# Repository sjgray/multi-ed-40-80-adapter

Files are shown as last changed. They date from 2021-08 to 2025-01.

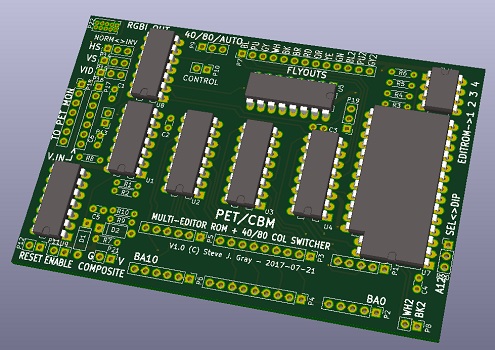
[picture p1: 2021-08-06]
multied4080.jpg

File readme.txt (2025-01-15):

PET/CBM Multi-EditROM with 40/80 column switcher Adapter
========================================================

This adapter lets your PET/CBM computer with Universal Dynamic PET motherboard
to have up to 16 Edit ROM available and selectable via DIP Switch or Toggle Switch.
and adds the ability for the video to be switched between 40 or 80 columns either
via software, or toggle switch (selectable).

Use my Multi-EDIT-ROM-Builder program (also available on github) to combine
up to 16 editor roms into a single 64K EPROM.

Use my PET/CBM EditROM Project to create custom Editor ROMs with various features
including software-switchable 40/80 column support via this board.

More information and assembly instructions at:
http://www.cbmsteve.ca
http://www.cbmsteve.ca/multied4080/index.html

Steve

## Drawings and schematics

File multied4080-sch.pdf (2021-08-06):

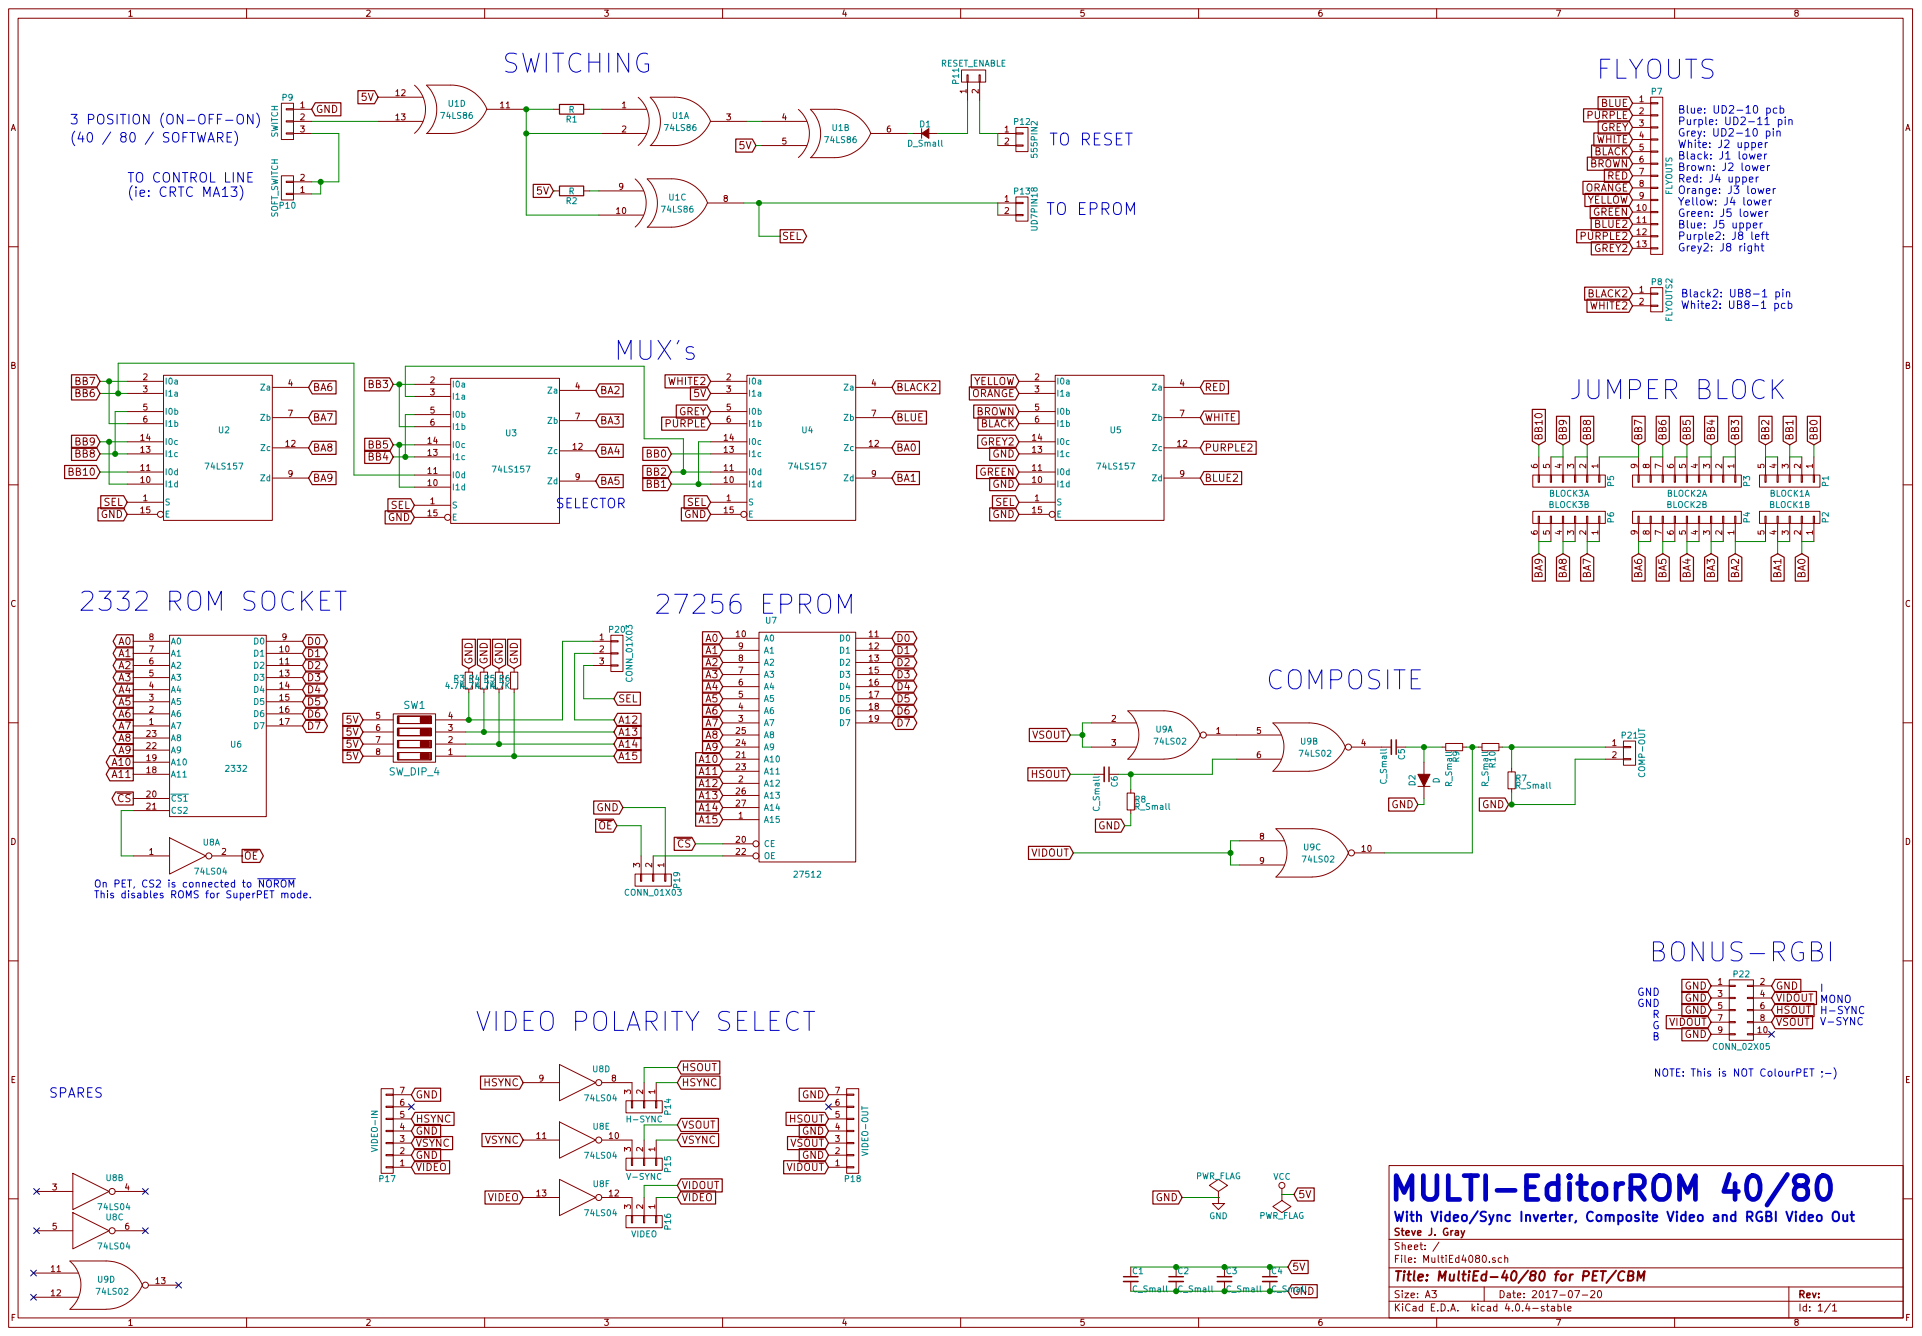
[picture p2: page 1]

3 POSITION (ON-OFF-ON)
(40 / 80 / SOFTWARE)

4.7K GND GND GND GND

On PET, CS2 is connected to NOROM
This disables ROMS for SuperPET mode.

NOTE: This is NOT ColourPET ;-)

File: MultiEd4080.sch Sheet: / Steve J. Gray

Id: 1/1 Title: MultiEd-40/80 for PET/CBM

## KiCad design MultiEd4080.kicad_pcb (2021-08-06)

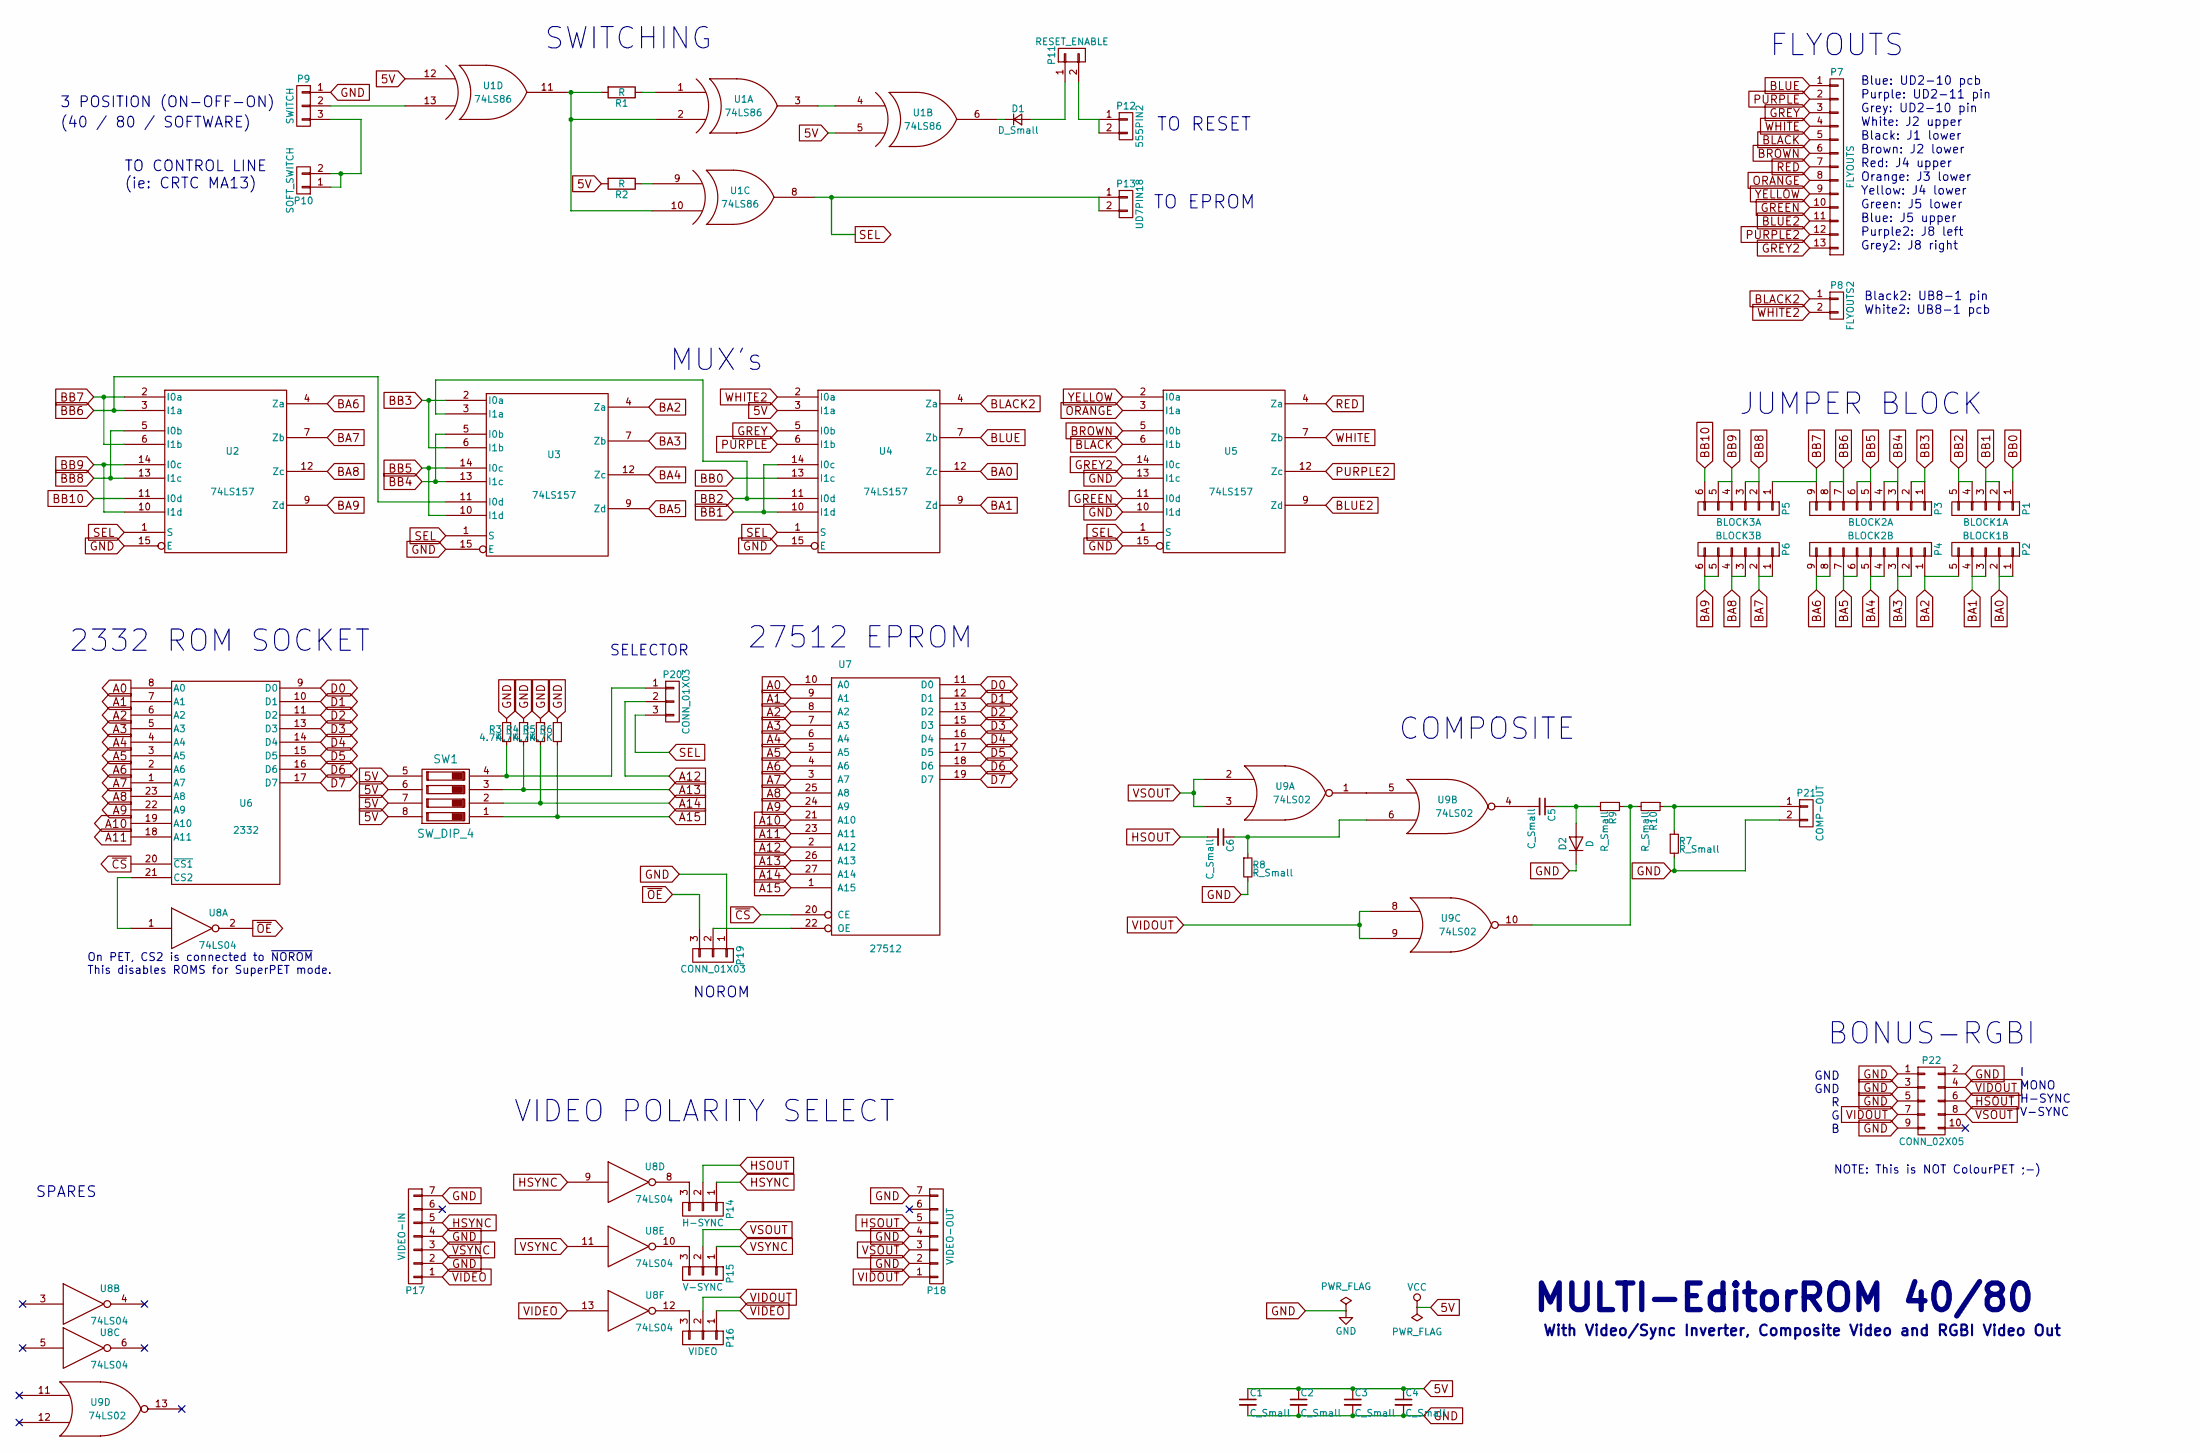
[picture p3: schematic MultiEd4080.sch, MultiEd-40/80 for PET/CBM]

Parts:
C1, C2, C3, C4, C5, C6: C_Small; C_Disc_D3.8mm_W2.6mm_P2.50mm
D1: D_Small; D_DO-41_SOD81_P7.62mm_Horizontal
D2: D; D_DO-41_SOD81_P7.62mm_Horizontal
P1: BLOCK1A; Pin_Header_Straight_1x05_Pitch2.54mm
P2: BLOCK1B; Pin_Header_Straight_1x05_Pitch2.54mm
P3: BLOCK2A; Pin_Header_Straight_1x09_Pitch2.54mm
P4: BLOCK2B; Pin_Header_Straight_1x09_Pitch2.54mm
P5: BLOCK3A; Pin_Header_Straight_1x06_Pitch2.54mm
P6: BLOCK3B; Pin_Header_Straight_1x06_Pitch2.54mm
P7: FLYOUTS; Pin_Header_Straight_1x13_Pitch2.54mm
P8: FLYOUTS2; Pin_Header_Straight_1x02_Pitch2.54mm
P9: SWITCH; Pin_Header_Straight_1x03_Pitch2.54mm
P10: SOFT_SWITCH; Pin_Header_Straight_1x02_Pitch2.54mm
P11: RESET_ENABLE; Pin_Header_Straight_1x02_Pitch2.54mm
P12: 555PIN2; Pin_Header_Straight_1x02_Pitch2.54mm
P13: UD7PIN18; Pin_Header_Straight_1x02_Pitch2.54mm
P14: H-SYNC; Pin_Header_Straight_1x03_Pitch2.54mm
P15: V-SYNC; Pin_Header_Straight_1x03_Pitch2.54mm
P16: VIDEO; Pin_Header_Straight_1x03_Pitch2.54mm
P17: VIDEO-IN; Pin_Header_Straight_1x07_Pitch2.54mm
P18: VIDEO-OUT; Pin_Header_Straight_1x07_Pitch2.54mm
P19, P20: CONN_01X03; Pin_Header_Straight_1x03_Pitch2.54mm
P21: COMP-OUT; Pin_Header_Straight_1x02_Pitch2.54mm
P22: CONN_02X05; Pin_Header_Straight_2x05_Pitch2.54mm
R1, R2: R; R_Axial_DIN0204_L3.6mm_D1.6mm_P5.08mm_Horizontal
R3, R4, R5, R6: 4.7K; R_Axial_DIN0204_L3.6mm_D1.6mm_P5.08mm_Horizontal
R7, R8, R9, R10: R_Small; R_Axial_DIN0204_L3.6mm_D1.6mm_P5.08mm_Horizontal
SW1: SW_DIP_4; DIP-8_W7.62mm_LongPads
U1: 74LS86; DIP-14_W7.62mm_LongPads
U2, U3, U4, U5: 74LS157; DIP-16_W7.62mm_LongPads
U6: 2332; DIP-24_W15.24mm_LongPads
U7: 27512; DIP-28_W15.24mm_LongPads
U8: 74LS04; DIP-14_W7.62mm_LongPads
U9: 74LS02; DIP-14_W7.62mm_LongPads

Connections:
5V: C1.1, C2.1, C3.1, C4.1, R2.2, SW1.5, SW1.6, SW1.7, SW1.8, U1.5 (IN2), U1.12 (IN1), U1.14 (VCC), U2.16 (VCC), U3.16 (VCC), U4.3 (I1a), U4.16 (VCC), U5.16 (VCC), U6.24 (Vcc), U7.28 (VCC), U8.14 (VCC), U9.14 (VCC)
A0: U6.8 (A0), U7.10 (A0)
A1: U6.7 (A1), U7.9 (A1)
A2: U6.6 (A2), U7.8 (A2)
A3: U6.5 (A3), U7.7 (A3)
A4: U6.4 (A4), U7.6 (A4)
A5: U6.3 (A5), U7.5 (A5)
A6: U6.2 (A6), U7.4 (A6)
A7: U6.1 (A7), U7.3 (A7)
A8: U6.23 (A8), U7.25 (A8)
A9: U6.22 (A9), U7.24 (A9)
A10: U6.19 (A10), U7.21 (A10)
A11: U6.18 (A11), U7.23 (A11)
A12: P20.2, U7.2 (A12)
A13: R4.2, SW1.3, U7.26 (A13)
A14: R5.2, SW1.2, U7.27 (A14)
A15: R6.2, SW1.1, U7.1 (A15)
BA0: P2.1, P2.2, U4.12 (Zc)
BA1: P2.3, P2.4, U4.9 (Zd)
BA2: P2.5, P4.1, U3.4 (Za)
BA3: P4.2, P4.3, U3.7 (Zb)
BA4: P4.4, P4.5, U3.12 (Zc)
BA5: P4.6, P4.7, U3.9 (Zd)
BA6: P4.8, P4.9, U2.4 (Za)
BA7: P6.1, P6.2, U2.7 (Zb)
BA8: P6.3, P6.4, U2.12 (Zc)
BA9: P6.5, P6.6, U2.9 (Zd)
BB0: P1.1, U4.13 (I1c)
BB1: P1.2, P1.3, U4.10 (I1d), U4.14 (I0c)
BB2: P1.4, P1.5, U3.3 (I1a), U4.11 (I0d)
BB3: P3.1, P3.2, U3.2 (I0a), U3.6 (I1b)
BB4: P3.3, P3.4, U3.5 (I0b), U3.13 (I1c)
BB5: P3.5, P3.6, U3.10 (I1d), U3.14 (I0c)
BB6: P3.7, P3.8, U2.3 (I1a), U3.11 (I0d)
BB7: P3.9, P5.1, U2.2 (I0a), U2.6 (I1b)
BB8: P5.2, P5.3, U2.5 (I0b), U2.13 (I1c)
BB9: P5.4, P5.5, U2.10 (I1d), U2.14 (I0c)
BB10: P5.6, U2.11 (I0d)
BLACK: P7.5, U5.6 (I1b)
BLACK2: P8.1, U4.4 (Za)
BLUE: P7.1, U4.7 (Zb)
BLUE2: P7.11, U5.9 (Zd)
BROWN: P7.6, U5.5 (I0b)
D0: U6.9 (D0), U7.11 (D0)
D1: U6.10 (D1), U7.12 (D1)
D2: U6.11 (D2), U7.13 (D2)
D3: U6.13 (D3), U7.15 (D3)
D4: U6.14 (D4), U7.16 (D4)
D5: U6.15 (D5), U7.17 (D5)
D6: U6.16 (D6), U7.18 (D6)
D7: U6.17 (D7), U7.19 (D7)
GND: C1.2, C2.2, C3.2, C4.2, D2.1 (K), P9.1, P17.2, P17.4, P17.7, P18.2, P18.4, P18.7, P19.1, P21.2, P22.1, P22.2, P22.3, P22.5, P22.9, R3.1, R4.1, R5.1, R6.1, R7.2, R8.2, U1.7 (GND), U2.8 (GND), U2.15 (E), U3.8 (GND), U3.15 (E), U4.8 (GND), U4.15 (E), U5.8 (GND), U5.10 (I1d), U5.13 (I1c), U5.15 (E), U6.12 (GND), U7.14 (GND), U8.7 (GND), U9.7 (GND)
GREEN: P7.10, U5.11 (I0d)
GREY: P7.3, U4.5 (I0b)
GREY2: P7.13, U5.14 (I0c)
HSOUT: C6.2, P14.2, P18.5, P22.6
HSYNC: P14.1, P17.5, U8.9
unnamed: C5.1, D2.2 (A), R9.2
unnamed: C5.2, U9.4
unnamed: C6.1, R8.1, U9.6
unnamed: D1.1 (K), U1.6 (OUT)
unnamed: D1.2 (A), P11.1
unnamed: P9.2, U1.13 (IN2)
unnamed: P9.3, P10.1, P10.2
unnamed: P11.2, P12.1, P12.2
unnamed: P14.3, U8.8
unnamed: P15.3, U8.10
unnamed: P16.3, U8.12
unnamed: P19.2, U7.22 (OE)
unnamed: P20.1, R3.2, SW1.4
unnamed: P21.1, R7.1, R10.1
unnamed: R1.1, U1.1 (IN1)
unnamed: R1.2, U1.2 (IN2), U1.10 (IN2), U1.11 (OUT)
unnamed: R2.1, U1.9 (IN1)
unnamed: R9.1, R10.2, U9.10
unnamed: U1.3 (OUT), U1.4 (IN1)
unnamed: U6.21 (CS2), U8.1
unnamed: U9.1, U9.5
ORANGE: P7.8, U5.3 (I1a)
PURPLE: P7.2, U4.6 (I1b)
PURPLE2: P7.12, U5.12 (Zc)
RED: P7.7, U5.4 (Za)
SEL: P13.1, P13.2, P20.3, U1.8 (OUT), U2.1 (S), U3.1 (S), U4.1 (S), U5.1 (S)
VIDEO: P16.1, P17.1, U8.13
VIDOUT: P16.2, P18.1, P22.4, P22.7, U9.8, U9.9
VSOUT: P15.2, P18.3, P22.8, U9.2, U9.3
VSYNC: P15.1, P17.3, U8.11
WHITE: P7.4, U5.7 (Zb)
WHITE2: P8.2, U4.2 (I0a)
YELLOW: P7.9, U5.2 (I0a)
~CS: U6.20 (~CS1), U7.20 (CE)
~OE: P19.3, U8.2

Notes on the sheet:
With Video/Sync Inverter, Composite Video and RGBI Video Out
SWITCHING
FLYOUTS
TO EPROM
TO RESET
JUMPER BLOCK
MUX's
Blue: UD2-10 pcb Purple: UD2-11 pin Grey: UD2-10 pin White: J2 upper Black: J1 lower Brown: J2 lower Red: J4 upper Orange: J3 lower Yellow: J4 lower Green: J5 lower Blue: J5 upper Purple2: J8 left Grey2: J8 right
Black2: UB8-1 pin White2: UB8-1 pcb
2332 ROM SOCKET
27512 EPROM
SELECTOR
MULTI-EditorROM 40/80
On PET, CS2 is connected to ~NOROM~ This disables ROMS for SuperPET mode.
SPARES
VIDEO POLARITY SELECT
3 POSITION (ON-OFF-ON)
TO CONTROL LINE (ie: CRTC MA13)
(40 / 80 / SOFTWARE)
COMPOSITE
BONUS-RGBI
GND GND R G B
I MONO H-SYNC V-SYNC
NOTE: This is NOT ColourPET ;-)
NOROM

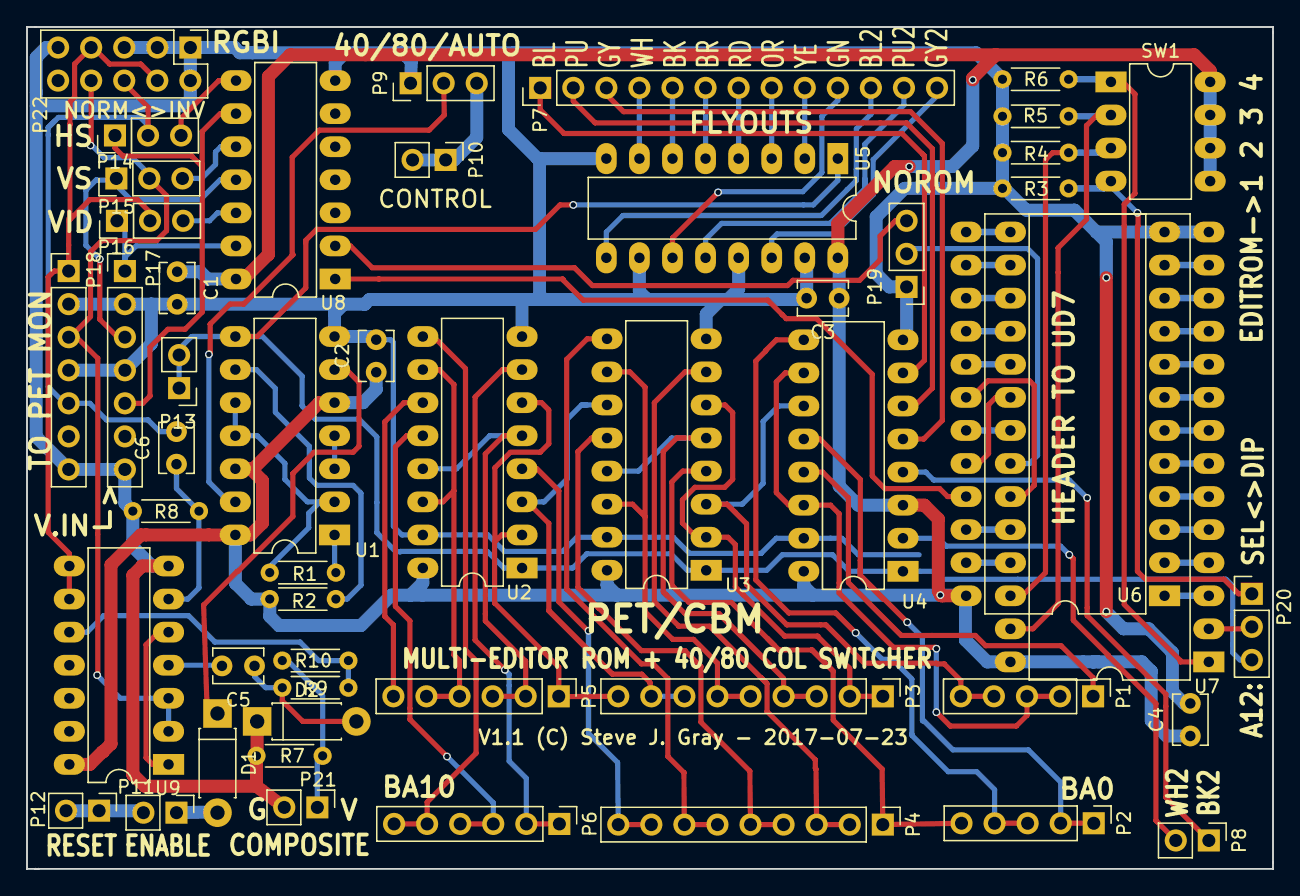
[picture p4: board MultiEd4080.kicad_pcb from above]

Board: 2 copper layers, 95.7 x 64.7 mm, 50 parts (0 on the bottom side), 92 nets.
